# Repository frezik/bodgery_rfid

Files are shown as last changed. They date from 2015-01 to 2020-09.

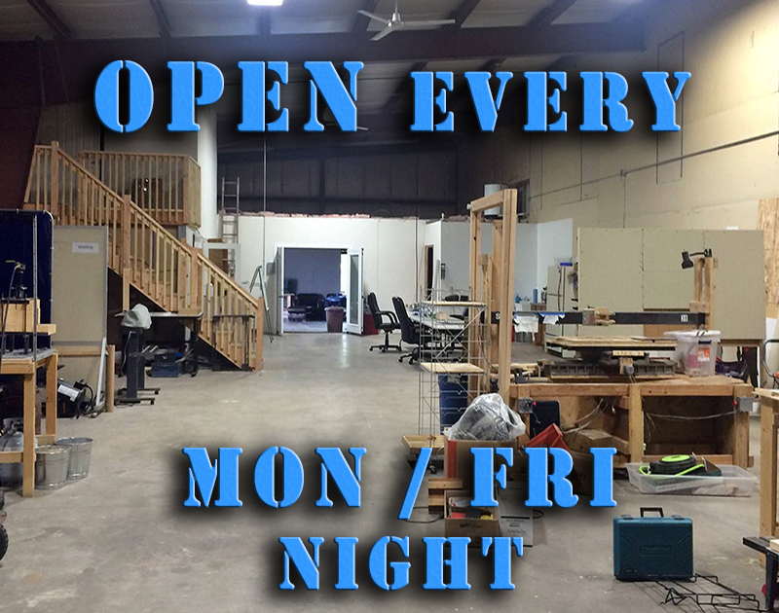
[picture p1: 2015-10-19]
feed.jpg

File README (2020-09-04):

RFID system for The Bodgery <http://thebodgery.org>

# INSTALL OF SERVER

Installation on a Ubuntu/Debian based Linux distribution:

* Clone the respository
* Install cpanminus and postgresql: `sudo apt-get install cpanminus postgres-all`
* Install dependencies: `sudo cpanm --installdeps`
* Install Starman: `sudo cpanm Starman`
* Create a user for postgresql
* Create a database in postgresql called "bodgery_rfid", with full access to 
  the user created above
* Create the tables in the database: `psql --file postgresql.sql bodgery_rfid`
* Run the server with starman: `starman --listen :3000 app.pl`

The server should now be accessible on localhost at port 3000.

# PINS

Pins Used on the Rpi Model B+.  Numbered by physical header, not GPIO number.

Pin     Function
---     --------
1       Open/closed door pushbutton switch power (3.3V)
7       LED open signal (GPIO4)
9       LED open signal ground (GND)
11      Open/closed door pushbutton switch (GPIO17)
13      Relay enable pin (GPIO27)
15      Lock Relay (GPIO22)
16      Open/closed shop toggle switch (GPIO23)
17      Open/closed shop toggle switch power (3V3)
22      Unlock Switch (GPIO25)
25      Relay ground (GND)

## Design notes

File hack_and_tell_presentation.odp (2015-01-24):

## Bodgery RFID

## Overview

- USB reader, like keyboard, 125kHz
  - Not NFC (13.56MHz)
- Door handle has solinoid, run by relay
- Raspberry Pi on UPS
- Server holds member database
- REST interface between server and Rpi
  - Mojolicious::Lite

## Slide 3

Demo Entry

## Rpi inittab

1:2345:respawn:/sbin/getty 38400 -n -l /path/to/reader_prog.pl tty1

2:23:respawn:/sbin/getty 38400 tty2

3:23:respawn:/sbin/getty 38400 tty3

4:23:respawn:/sbin/getty 38400 tty4

5:23:respawn:/sbin/getty 38400 tty5

6:23:respawn:/sbin/getty 38400 tty6

## REST

[Show app.pl]

## Piezo

use Time::HiRes 'sleep';

my @notes = qw{ 1568 1480 1245 880 831 1319 1661

2093 };

HiPi::Wiring::softToneCreate( $PIN );

foreach (@notes) {

HiPi::Wiring::softToneWrite( $PIN, $_ );

sleep( 0.2 );

}

HiPi::Wiring::softToneWrite( $PIN, 0 );

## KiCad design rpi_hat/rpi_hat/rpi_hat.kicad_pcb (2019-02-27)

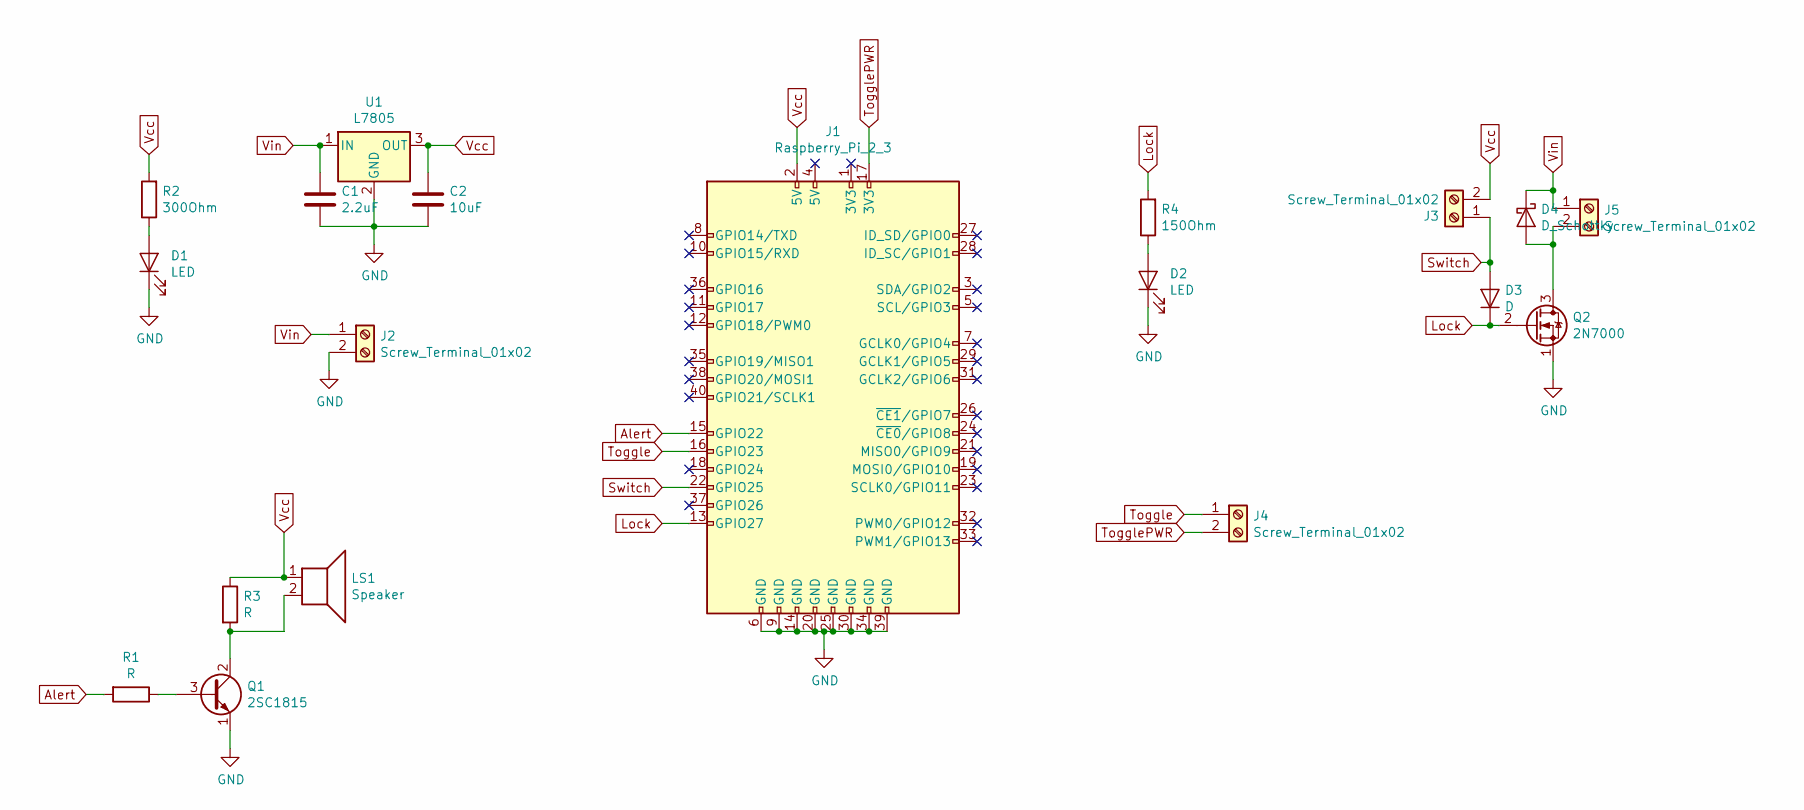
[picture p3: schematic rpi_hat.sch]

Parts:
C1: 2.2uF; C_0402; Digikey # 490-12532-1-ND
C2: 10uF; C_0805; Digikey # 1276-6456-1-ND
D1: LED; LED_0603; Digikey # SML-D12U1WT86CT-ND
D2: LED; LED_0603; Digikey # 160-1478-1-ND
D3: D; SOD-123; Digikey # 1N4148WTPMSCT-ND
D4: D_Schottky; SOD-123; Digikey # MBR0540T3GOSCT-ND
J1: Raspberry_Pi_2_3; Pin_Header_Straight_2x20; Digikey # 1528-1785-ND
J2, J3, J4, J5: Screw_Terminal_01x02; TerminalBlock_Pheonix_MKDS1.5-2pol; Digikey # 277-1667-ND
LS1: Speaker; PS1240P02BT; Digikey # 445-2525-1-ND
Q1: 2SC1815; TO-92_Inline_Wide; Digikey # KSC1815YTACT-ND
Q2: 2N7000; TO-220_Neutral123_Horizontal; Digikey # 497-2779-5-ND
R1, R3: R; R_0805; Digikey # RNCP0805FTD1K00CT-ND
R2: 300Ohm; R_2512; Digikey # RMCF2512JT300RCT-ND
R4: 150Ohm; R_0603; Digikey # P150DBCT-ND
U1: L7805; Pin_Header_Angled_1x03; Digikey # 1589-1465-ND

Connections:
Alert: J1.15 (GPIO22), R1.2
GND: C1.2, C2.2, D1.1 (K), D2.1 (K), J1.6 (GND), J1.9 (GND), J1.14 (GND), J1.20 (GND), J1.25 (GND), J1.30 (GND), J1.34 (GND), J1.39 (GND), J2.2, Q1.1 (E), Q2.1 (S), U1.2 (GND)
Lock: D3.1 (K), J1.13 (GPIO27), Q2.2 (G), R4.2
unnamed: D1.2 (A), R2.1
unnamed: D2.2 (A), R4.1
unnamed: D4.2 (A), J5.2, Q2.3 (D)
unnamed: LS1.2, Q1.2 (C), R3.2
unnamed: Q1.3 (B), R1.1
Switch: D3.2 (A), J1.22 (GPIO25), J3.1
Toggle: J1.16 (GPIO23), J4.1
TogglePWR: J1.17 (3V3), J4.2
Vcc: C2.1, J1.2 (5V), J3.2, LS1.1, R2.2, R3.1, U1.3 (OUT)
Vin: C1.1, D4.1 (K), J2.1, J5.1, U1.1 (IN)

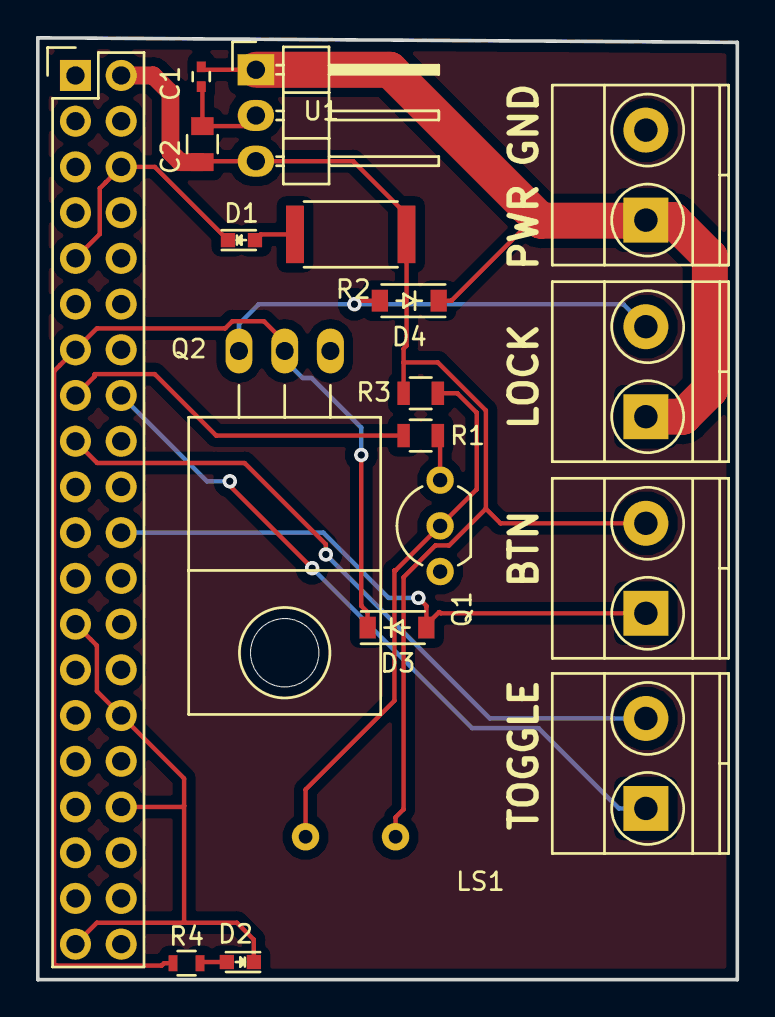
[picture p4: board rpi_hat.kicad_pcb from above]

Board: 2 copper layers, 38.9 x 52.3 mm, 19 parts (0 on the bottom side), 13 nets.

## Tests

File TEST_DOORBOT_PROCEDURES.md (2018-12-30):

Hit button
Door unlocked for 30 seconds

Scan key
Door unlocked for 30 seconds

Hold button and scan key
Door unlocked for awhile
Hold button and scan key again
Door locked

Hold button and scan key
Door unlocked for awhile
Hit button
Nothing happens, even after 30 seconds

Hold button and scan key
Door unlocked for awhile
Scan key
Nothing happens, even after 30 seconds

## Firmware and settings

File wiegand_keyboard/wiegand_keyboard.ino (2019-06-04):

/* Marshall Scholz
 * uses a teensy to turn 26 bit rfid reader wiegand communication into a
 * keyboard number string that is identical to
 * off the shelf usb rfid readers.
 *
 * the led blinks when a card is read.
 *
 * wigand is a 5v protocol, but the teensy is a 3.3v ic.
 * you must use a logic level converter between the reader and teensy.
 *
 * data0 = pin 10
 * data1 = pin 11
*/


// wigand library from here: https://github.com/monkeyboard/Wiegand-Protocol-Library-for-Arduino/blob/master/README.md
#include <Wiegand.h>
//#include "Keyboard.h" // for leonardo only. select "keyboard" in usb type for teensy

// Need to send a set string length, with leading zeros if there isn't
// enough
#define TARGET_STRING_LEN 10


WIEGAND wg;
int led = 13;


void setup()
{
    Serial.begin(9600);

    // default Wiegand Pin 2 and Pin 3 see image on README.md
    // for non UNO board, use wg.begin(pinD0, pinD1) where pinD0 and pinD1
    // are the pins connected to D0 and D1 of wiegand reader respectively.
    pinMode( led, OUTPUT );
    digitalWrite( led, HIGH );
    wg.begin( 10, 11 );

    delay( 1000 );
    digitalWrite( led, LOW );
}

void loop()
{
    if( wg.available() ) {
        digitalWrite( led, HIGH );
        String idstring = String( wg.getCode() );

        // If the length ends up being larger than the target, that's OK,
        // num_zeros will just be negative, and the for() loop won't add 
        // anything. We just end up sending the string verbatim below.
        int num_zeros = TARGET_STRING_LEN - idstring.length();
        String zero_pad = String( "" );
        for( int i = 0; i < num_zeros; i++ ) {
            zero_pad.concat( "0" );
        }

        Keyboard.print( zero_pad );
        Keyboard.println( idstring );

        digitalWrite( led, LOW );
	}
}

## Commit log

2014-12-22 Initial import
    [budget.ods]
2014-12-22 Update numbers for RPi-based solution
    [budget.ods]
2014-12-29 * Add power adaptor circuit * Page for adding new RFID tag * Add calls for searching tags and entry log * Flesh out index definitions * Flesh out client action breakdown
    [power_adaptor.sch]
2014-12-29 Page for viewing member list. When searching name, do it in a case-insensitive manner, with a prefix search
2014-12-29 Activate/deactivate buttons work
2014-12-29 Clear current TODO list
2014-12-31 Remove budget doc
    [budget.ods]
2015-01-02 Add --test parameter. Don't die when we get an error from the server.
2015-03-14 Fix unlock LED and LCD
2015-03-23 Move LCD power off a GPIO pin
2015-06-12 Add GPIO info to pin description
2015-06-12 Add piezo pin
2015-06-24 Change relay to switch
2015-08-13 Hold door open for 10 seconds when open button pushed
2015-09-01 Implement script for fetching pic when shop is open. Define a client pin for shop open switch.
2015-10-08 App's caching of door state uses CHI backend. Clear away LCD, piezo, and picture taking code in client. Also, hold door open if a tag is scanned after pushing the exit button.
2015-11-14 Add open switch code
2015-11-14 Update open/closed shop switch
2016-07-02 Add cpanfile to track deps
2016-07-12 App accepts updating of cost buckets
2017-01-21 Add temperature logging
2017-02-25 Name pin usage a little better
2017-02-25 Remove music. Set pullup on switch pin
2017-02-26 Debug systemd service file. Pushbutton connected to power.
2018-12-30 Hold door open by holding button while scanning. Close it again by doing the same.
2019-01-04 When canceling a hold open, don't let new timer activate for the button
2019-02-26 PCB for an RPi hat
    [rpi_hat.kicad_pcb, rpi_hat.sch]
2019-02-26 Fix pushbutton switch circuit so it doesn't rely on the Pi working
    [rpi_hat.kicad_pcb, rpi_hat.sch]
2019-02-26 Correct digikey part # for piezo transistor
    [rpi_hat.sch]
2019-02-27 Add protection diode
    [rpi_hat.kicad_pcb, rpi_hat.sch]
2019-06-02 Be sure to short-circuit the check when we successfully hit a key in the cache DB
2019-06-02 Marshall's wiegand -> USB keyboard bridge for Teensy
